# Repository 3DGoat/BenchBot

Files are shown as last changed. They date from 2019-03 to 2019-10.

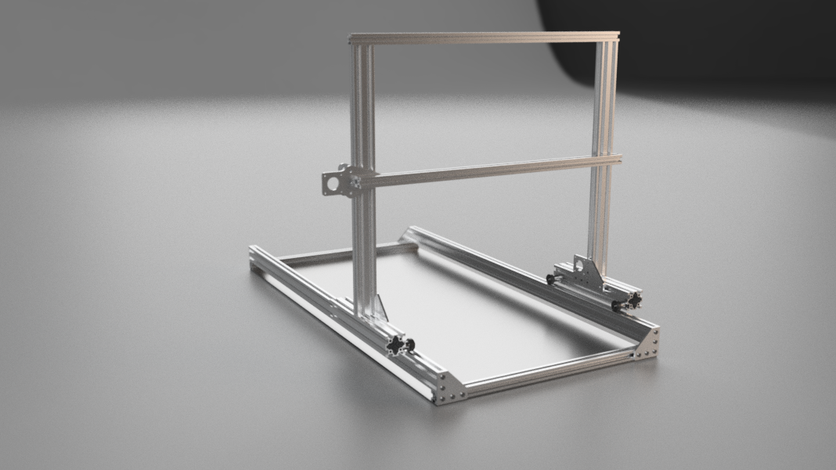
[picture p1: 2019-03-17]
Full Build v24 (2).png

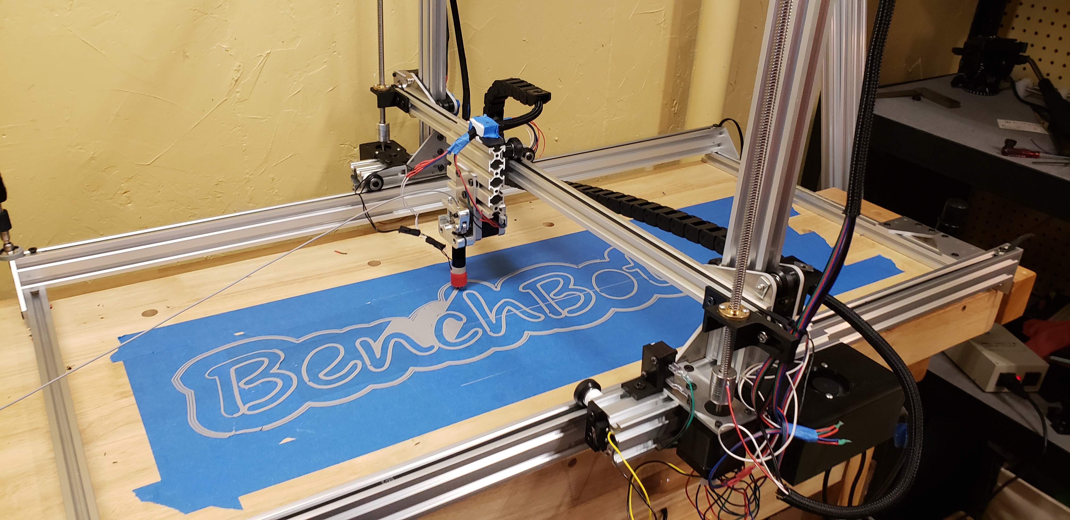
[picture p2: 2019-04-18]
20190323_132628.jpg

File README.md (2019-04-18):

# BenchBot
A large format 3D printer built specifically for a workbench. If files are marked experimental or untested that means that I have not tested them or they do not work. If files are unmarked you can assume that they will work.

Main sheet metal parts can be used on almost any length of aluminum extrusion.
Openbuilds 20x20,20x40 is suggested for this build. All metal parts are made for M5 screws and cheap v-slot wheels found on amazon
Sheet metal parts can be printed, but for best rigidity sheet metal would be suggested.

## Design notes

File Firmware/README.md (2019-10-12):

# Firmware

## 1.1.1
  Firmware made for full sized Benchbot.
  - Reverse logic for endstops (for manual homeing)
  - Steps/mm X,Y,Z,E  160, 80, 400, 96
  - Thermal settings set for Ubis 13s
  
## 1.1.2
  Firmware made for full sized Benchbot
  - Currently tested
    - Does not work with BLTouch
  - Default logic for enstops
  - Z settings made for BLTouch with mesh bed leveling
  - Steps/mm X,Y,Z,E  160, 80, 400, 96
  - Thermal settings set for Ubis 13s

## 1.1.3
   Firmware made for full sized Benchbot
  - Currently tested
  - Reverse logic for enstops
  - Z settings made for BLTouch with mesh bed leveling 4*4
  - Steps/mm X,Y,Z,E  160, 80, 400, 96
  - Thermal settings set for Ubis 13s
  - Last Version of Marlin
  
## 2.0 Duet wifi Config
   Firmware made for full sized BenchBot 
   - Currently Tested
   - Made for manual hinge Z-probe
   - Steps/mm X,Y,Z,E  160, 80, 400, 96
   - Thermal settings set for Ubis 13s
   - Sugguested mesh bed leveling spacing X=30 Y20

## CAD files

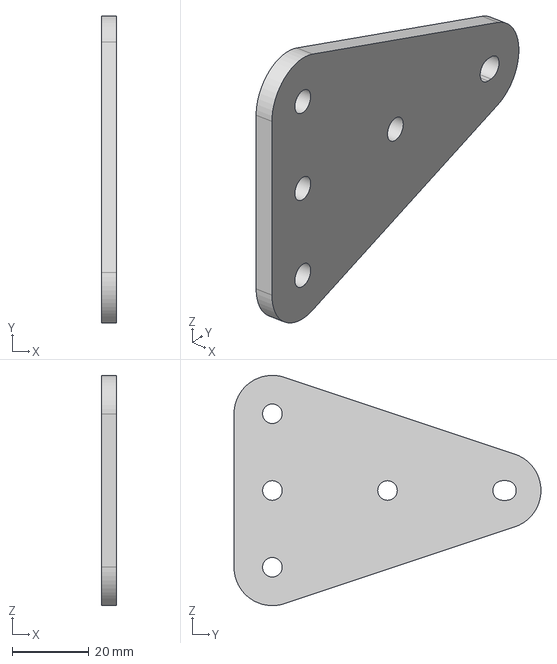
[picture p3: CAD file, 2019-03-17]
BenchBot CAD/Sheet Metal Parts/Main Y block v1.step
4.00 x 80.0 x 60.0 mm

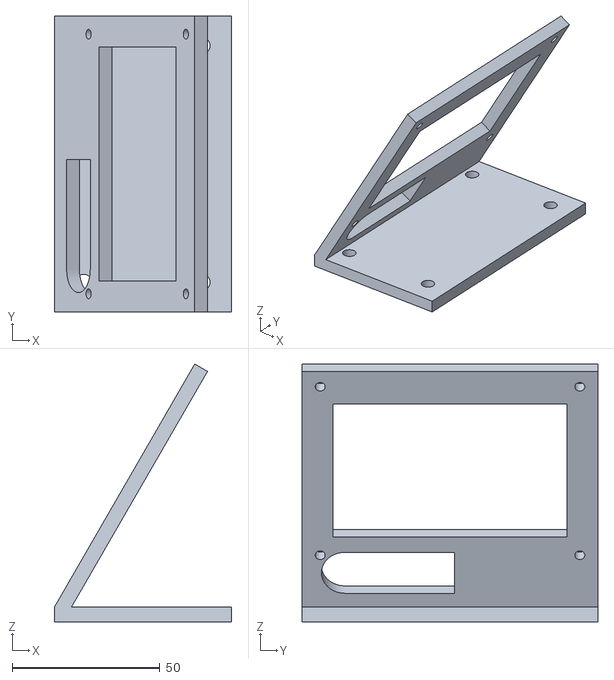
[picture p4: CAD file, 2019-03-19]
BenchBot CAD/Experimental parts/Controller.stl
60.0 x 100.0 x 87.3

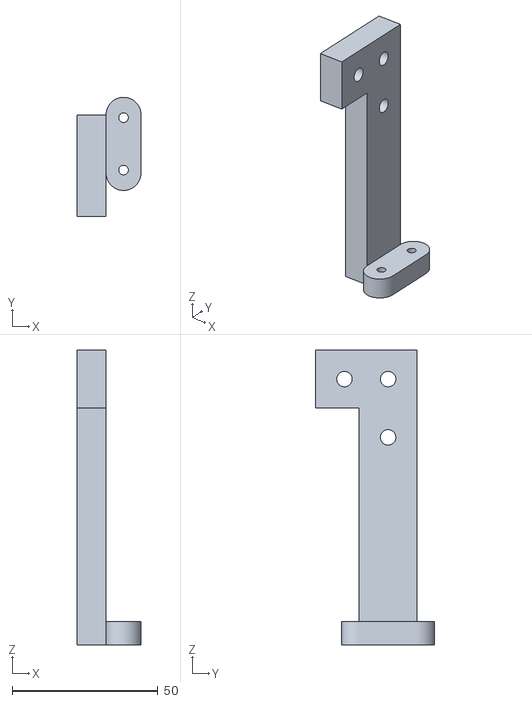
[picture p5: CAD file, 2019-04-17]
BenchBot CAD/STLs/Bltouch mount v2.stl
22.0 x 41.0 x 101.3

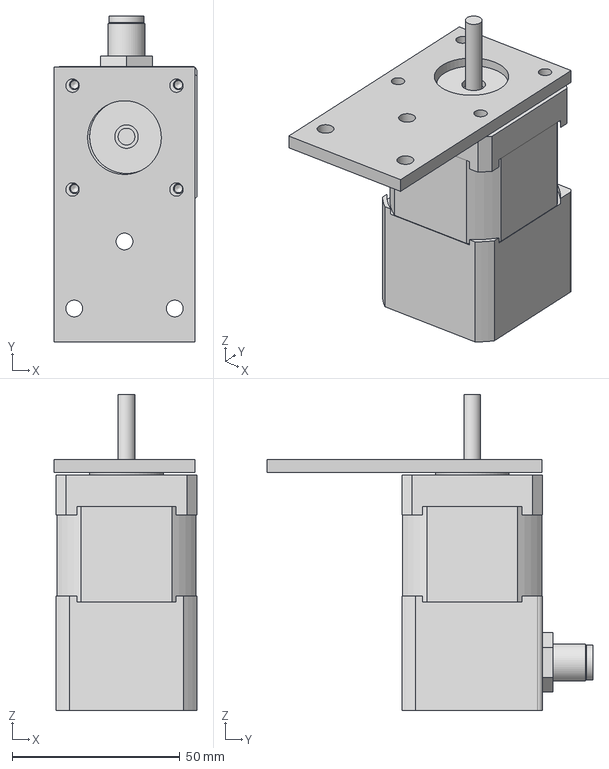
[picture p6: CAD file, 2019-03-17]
BenchBot CAD/Sheet Metal Parts/T-slot Stepper.step
42.6 x 97.3 x 94.4 mm

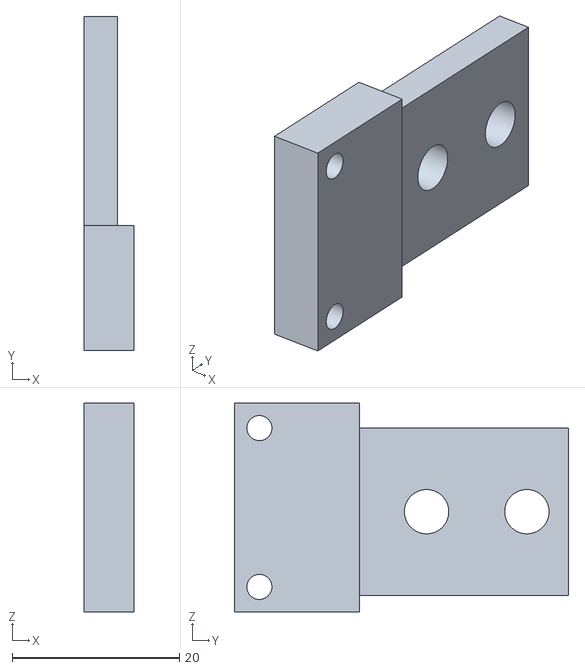
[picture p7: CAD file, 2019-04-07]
BenchBot CAD/STLs/Y endstop.stl
6.00 x 40.0 x 25.0

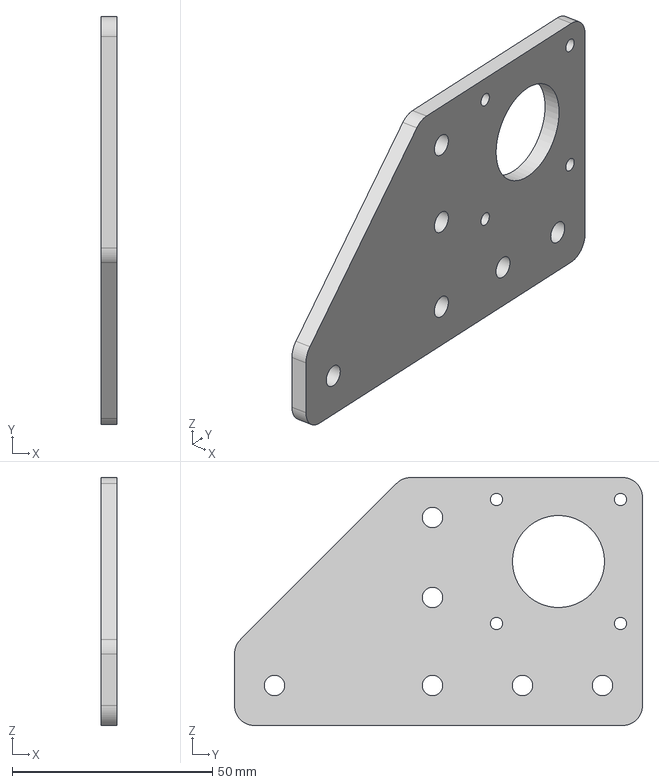
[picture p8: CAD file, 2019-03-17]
BenchBot CAD/Sheet Metal Parts/Bottom Gantry v5.step
4.00 x 102.0 x 62.0 mm

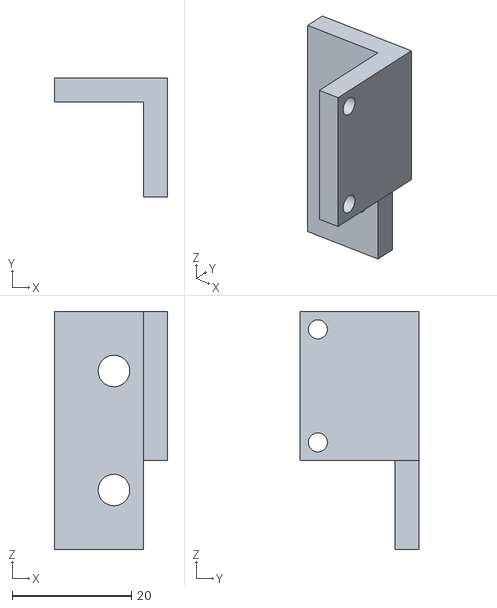
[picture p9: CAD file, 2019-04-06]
BenchBot CAD/STLs/X endstop.stl
19.0 x 20.0 x 40.0

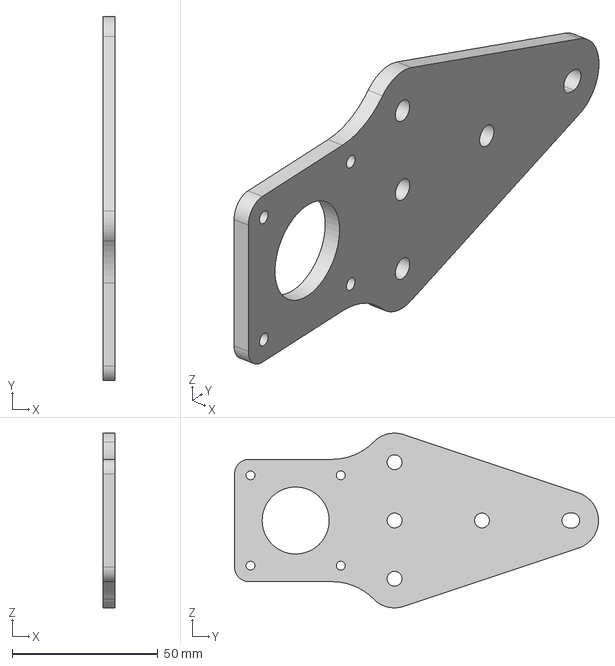
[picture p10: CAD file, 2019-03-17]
BenchBot CAD/Sheet Metal Parts/Motor Y block v3.step
4.00 x 125.0 x 60.0 mm

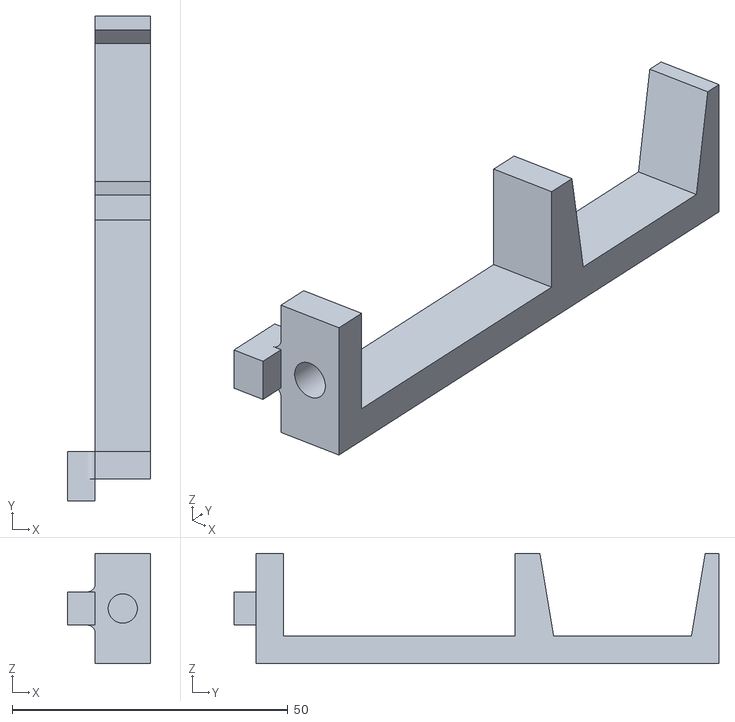
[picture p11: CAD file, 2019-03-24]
BenchBot CAD/STLs/Cable Chain Support.stl
15.0 x 88.0 x 20.0

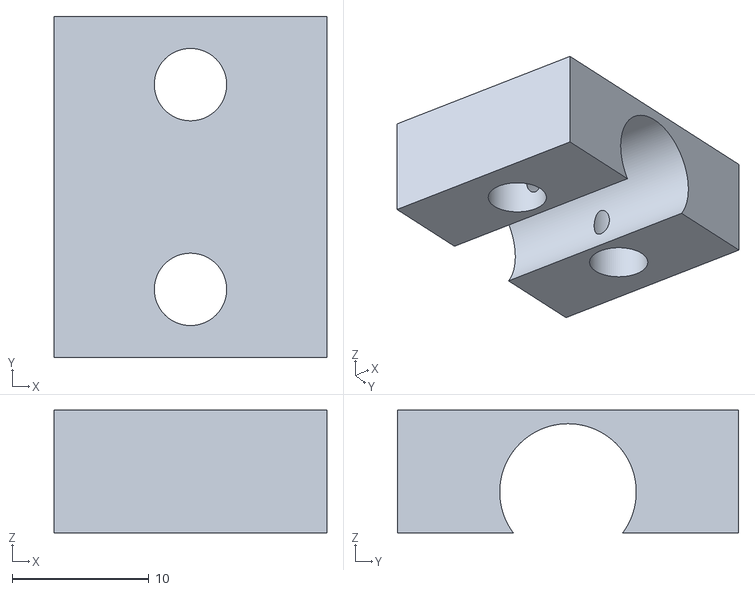
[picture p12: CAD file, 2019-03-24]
BenchBot CAD/STLs/Cable Chain Mount Y Strain Relief.stl
20.0 x 25.0 x 9.00

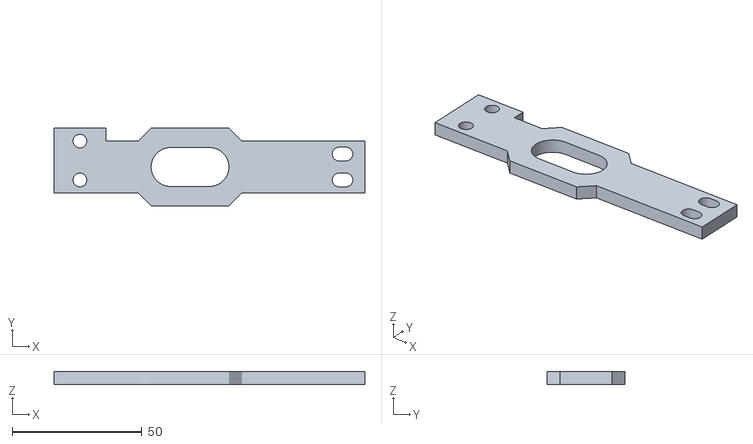
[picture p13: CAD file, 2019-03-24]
BenchBot CAD/STLs/Cable Chain Mount Y.stl
120.0 x 30.0 x 5.00

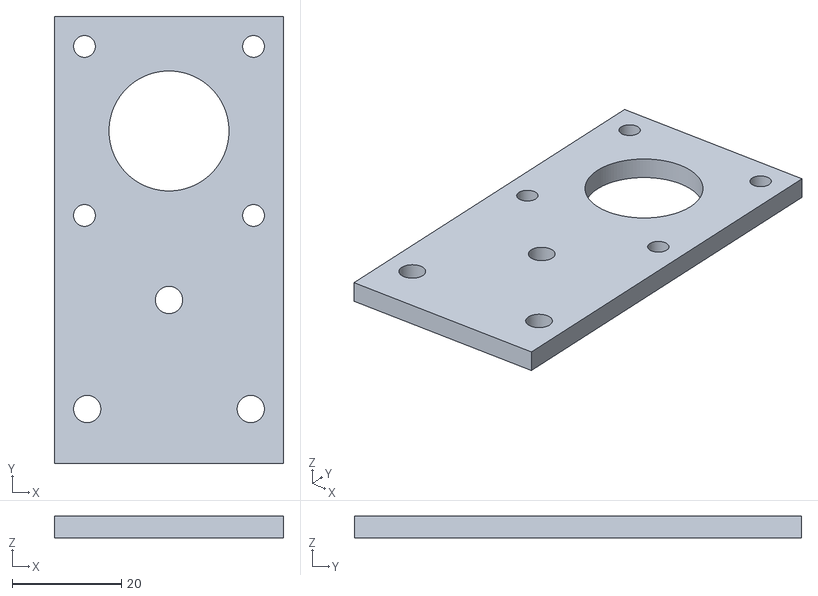
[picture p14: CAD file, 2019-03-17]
BenchBot CAD/STLs/T-slot Stepper.stl
42.0 x 82.0 x 4.00

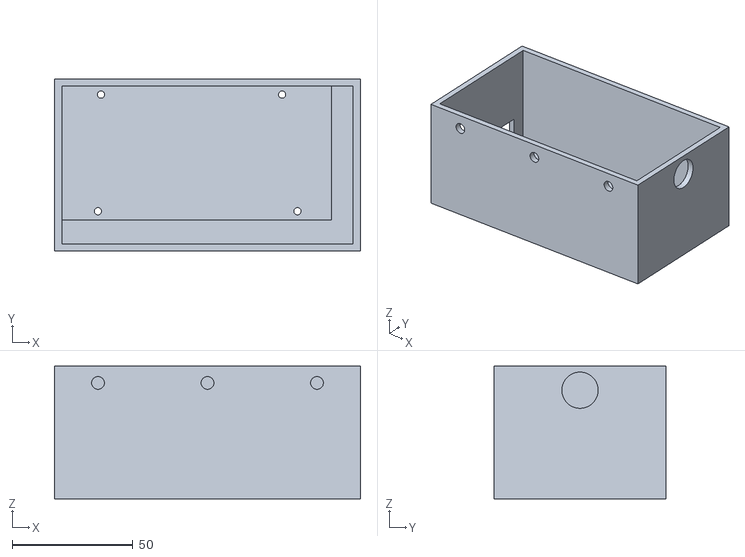
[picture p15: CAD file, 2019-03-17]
BenchBot CAD/STLs/RAMPS case BOTTOM.stl
126.6 x 71.3 x 55.0

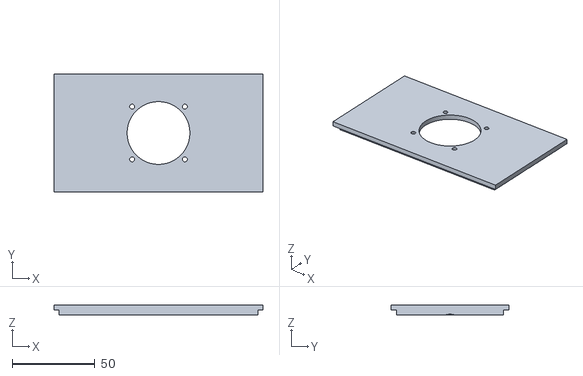
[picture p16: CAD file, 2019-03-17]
BenchBot CAD/STLs/RAMPS case TOP.stl
126.6 x 71.3 x 6.00

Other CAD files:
BenchBot CAD/Experimental parts/Y main block LIGHT.stl
BenchBot CAD/Experimental parts/Light Main Y block v2.step
BenchBot CAD/STLs/Main Y block V3.stl
BenchBot CAD/STLs/Motor Y Block V3.stl
BenchBot CAD/STLs/T-Slot Clip.stl
BenchBot CAD/STLs/Y Belt.stl
BenchBot CAD/STLs/Z Nut Y belt-end.stl

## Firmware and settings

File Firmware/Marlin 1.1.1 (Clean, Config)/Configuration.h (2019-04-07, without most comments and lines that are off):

#define CONFIGURATION_H
#define CONFIGURATION_H_VERSION 010109
#define STRING_CONFIG_H_AUTHOR "(none, default config)" // Who made the changes.
#define SHOW_BOOTSCREEN
#define STRING_SPLASH_LINE1 SHORT_BUILD_VERSION // will be shown during bootup in line 1
#define STRING_SPLASH_LINE2 WEBSITE_URL         // will be shown during bootup in line 2
#define SERIAL_PORT 0
#define BAUDRATE 250000
  #define MOTHERBOARD BOARD_RAMPS_14_EFF
#define CUSTOM_MACHINE_NAME "Bench Bot"
#define EXTRUDERS 1
#define DEFAULT_NOMINAL_FILAMENT_DIA 1.75
#define POWER_SUPPLY 0
#define TEMP_SENSOR_0 1
#define TEMP_SENSOR_1 0
#define TEMP_SENSOR_2 0
#define TEMP_SENSOR_3 0
#define TEMP_SENSOR_4 0
#define TEMP_SENSOR_BED 0
#define TEMP_SENSOR_CHAMBER 0
#define DUMMY_THERMISTOR_998_VALUE 25
#define DUMMY_THERMISTOR_999_VALUE 100
#define MAX_REDUNDANT_TEMP_SENSOR_DIFF 10
#define TEMP_RESIDENCY_TIME 10  // (seconds)
#define TEMP_HYSTERESIS 3       // (degC) range of +/- temperatures considered "close" to the target one
#define TEMP_WINDOW     1       // (degC) Window around target to start the residency timer x degC early.
#define TEMP_BED_RESIDENCY_TIME 10  // (seconds)
#define TEMP_BED_HYSTERESIS 3       // (degC) range of +/- temperatures considered "close" to the target one
#define TEMP_BED_WINDOW     1       // (degC) Window around target to start the residency timer x degC early.
#define HEATER_0_MINTEMP 5
#define HEATER_1_MINTEMP 5
#define HEATER_2_MINTEMP 5
#define HEATER_3_MINTEMP 5
#define HEATER_4_MINTEMP 5
#define BED_MINTEMP 5
#define HEATER_0_MAXTEMP 250
#define HEATER_1_MAXTEMP 275
#define HEATER_2_MAXTEMP 275
#define HEATER_3_MAXTEMP 275
#define HEATER_4_MAXTEMP 275
#define BED_MAXTEMP 150
#define PIDTEMP
#define BANG_MAX 255     // Limits current to nozzle while in bang-bang mode; 255=full current
#define PID_MAX BANG_MAX // Limits current to nozzle while PID is active (see PID_FUNCTIONAL_RANGE below); 255=full current
#define PID_K1 0.95      // Smoothing factor within any PID loop
  #define PID_FUNCTIONAL_RANGE 10 // If the temperature difference between the target temperature and the actual temperature
  #define DEFAULT_Kp 22.2
  #define DEFAULT_Ki 1.08
  #define DEFAULT_Kd 114
#define MAX_BED_POWER 255 // limits duty cycle to bed; 255=full current
#define PREVENT_COLD_EXTRUSION
#define EXTRUDE_MINTEMP 170
#define PREVENT_LENGTHY_EXTRUDE
#define EXTRUDE_MAXLENGTH 200
#define THERMAL_PROTECTION_HOTENDS // Enable thermal protection for all extruders
#define THERMAL_PROTECTION_BED     // Enable thermal protection for the heated bed
#define USE_XMIN_PLUG
#define USE_YMIN_PLUG
#define USE_ZMIN_PLUG
#define ENDSTOPPULLUPS
#define X_MIN_ENDSTOP_INVERTING true // set to true to invert the logic of the endstop.
#define Y_MIN_ENDSTOP_INVERTING true // set to true to invert the logic of the endstop.
#define Z_MIN_ENDSTOP_INVERTING true // set to true to invert the logic of the endstop.
#define X_MAX_ENDSTOP_INVERTING false // set to true to invert the logic of the endstop.
#define Y_MAX_ENDSTOP_INVERTING false // set to true to invert the logic of the endstop.
#define Z_MAX_ENDSTOP_INVERTING false // set to true to invert the logic of the endstop.
#define Z_MIN_PROBE_ENDSTOP_INVERTING false // set to true to invert the logic of the probe.
#define X_DRIVER_TYPE  A4988
#define Y_DRIVER_TYPE  A4988
#define DEFAULT_AXIS_STEPS_PER_UNIT   { 160, 80, 400, 96 }
#define DEFAULT_MAX_FEEDRATE          { 120, 200, 10, 25 }
#define DEFAULT_MAX_ACCELERATION      { 301, 1000, 100, 10000 }
#define DEFAULT_ACCELERATION          150    // X, Y, Z and E acceleration for printing moves
#define DEFAULT_RETRACT_ACCELERATION  3000    // E acceleration for retracts
#define DEFAULT_TRAVEL_ACCELERATION   175    // X, Y, Z acceleration for travel (non printing) moves
#define DEFAULT_XJERK                  5.0
#define DEFAULT_YJERK                 10.0
#define DEFAULT_ZJERK                  0.3
#define DEFAULT_EJERK                  5.0
#define PROBE_MANUALLY
#define MANUAL_PROBE_START_Z 0.2
#define X_PROBE_OFFSET_FROM_EXTRUDER 10  // X offset: -left  +right  [of the nozzle]
#define Y_PROBE_OFFSET_FROM_EXTRUDER 10  // Y offset: -front +behind [the nozzle]
#define Z_PROBE_OFFSET_FROM_EXTRUDER 0   // Z offset: -below +above  [the nozzle]
#define MIN_PROBE_EDGE 10
#define XY_PROBE_SPEED 3600
#define Z_PROBE_SPEED_FAST HOMING_FEEDRATE_Z
#define Z_PROBE_SPEED_SLOW (Z_PROBE_SPEED_FAST / 2)
#define Z_CLEARANCE_DEPLOY_PROBE   10 // Z Clearance for Deploy/Stow
#define Z_CLEARANCE_BETWEEN_PROBES  5 // Z Clearance between probe points
#define Z_CLEARANCE_MULTI_PROBE     5 // Z Clearance between multiple probes
#define Z_PROBE_LOW_POINT          -2 // Farthest distance below the trigger-point to go before stopping
#define Z_PROBE_OFFSET_RANGE_MIN -20
#define Z_PROBE_OFFSET_RANGE_MAX 20
#define X_ENABLE_ON 0
#define Y_ENABLE_ON 0
#define Z_ENABLE_ON 0
#define E_ENABLE_ON 0 // For all extruders
#define DISABLE_X false
#define DISABLE_Y false
#define DISABLE_Z false
#define DISABLE_E false // For all extruders
#define DISABLE_INACTIVE_EXTRUDER true // Keep only the active extruder enabled.
#define INVERT_X_DIR false
#define INVERT_Y_DIR true
#define INVERT_Z_DIR false
#define INVERT_E0_DIR false
#define INVERT_E1_DIR false
#define INVERT_E2_DIR false
#define INVERT_E3_DIR false
#define INVERT_E4_DIR false
#define X_HOME_DIR -1
#define Y_HOME_DIR -1
#define Z_HOME_DIR -1
#define X_BED_SIZE 690
#define Y_BED_SIZE 440
#define X_MIN_POS 0
#define Y_MIN_POS 0
#define Z_MIN_POS 0
#define X_MAX_POS X_BED_SIZE
#define Y_MAX_POS Y_BED_SIZE
#define Z_MAX_POS 250
#define MIN_SOFTWARE_ENDSTOPS
  #define MIN_SOFTWARE_ENDSTOP_X
  #define MIN_SOFTWARE_ENDSTOP_Y
  #define MIN_SOFTWARE_ENDSTOP_Z
#define MAX_SOFTWARE_ENDSTOPS
  #define MAX_SOFTWARE_ENDSTOP_X
  #define MAX_SOFTWARE_ENDSTOP_Y
  #define MAX_SOFTWARE_ENDSTOP_Z
#define MESH_BED_LEVELING
  #define ENABLE_LEVELING_FADE_HEIGHT
  #define SEGMENT_LEVELED_MOVES
  #define LEVELED_SEGMENT_LENGTH 5.0 // (mm) Length of all segments (except the last one)
  #define MESH_INSET 10          // Set Mesh bounds as an inset region of the bed
  #define GRID_MAX_POINTS_X 3    // Don't use more than 7 points per axis, implementation limited.
  #define GRID_MAX_POINTS_Y GRID_MAX_POINTS_X
#define LCD_BED_LEVELING
  #define MBL_Z_STEP 0.1    // Step size while manually probing Z axis.
  #define LCD_PROBE_Z_RANGE 4 // Z Range centered on Z_MIN_POS for LCD Z adjustment
#define MANUAL_X_HOME_POS 0
#define MANUAL_Y_HOME_POS 0
#define MANUAL_Z_HOME_POS 0
#define HOMING_FEEDRATE_XY (50*60)
#define HOMING_FEEDRATE_Z  (4*60)
#define EEPROM_CHITCHAT   // Give feedback on EEPROM commands. Disable to save PROGMEM.
#define HOST_KEEPALIVE_FEATURE        // Disable this if your host doesn't like keepalive messages
#define DEFAULT_KEEPALIVE_INTERVAL 2  // Number of seconds between "busy" messages. Set with M113.
#define BUSY_WHILE_HEATING            // Some hosts require "busy" messages even during heating
#define PREHEAT_1_TEMP_HOTEND 180
#define PREHEAT_1_TEMP_BED      0
#define PREHEAT_1_FAN_SPEED     0 // Value from 0 to 255
#define PREHEAT_2_TEMP_HOTEND 240
#define PREHEAT_2_TEMP_BED      0
#define PREHEAT_2_FAN_SPEED     0 // Value from 0 to 255
#define PRINTJOB_TIMER_AUTOSTART
#define LCD_LANGUAGE en
#define DISPLAY_CHARSET_HD44780 JAPANESE
#define SDSUPPORT
#define SPI_SPEED SPI_HALF_SPEED
#define REPRAP_DISCOUNT_FULL_GRAPHIC_SMART_CONTROLLER
#define SOFT_PWM_SCALE 0
#define SERVO_DELAY { 300 }

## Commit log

2019-03-17 Create CAD
2019-03-17 Most CAD files for the printer
    Sheet metal parts have holes made for M5, they are all 5.1mm witch is a bit tight for most manufacturing facilities.
    [Bottom Gantry v5.step, Main Y block V3.stl, Main Y block v1.step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]
2019-03-17 The Experimental Zone
    These parts have not been tested/printed by myself, so there may be large errors.
    Y block light is designed to be threaded on two of the wheel mounting holes.
    [Light Main Y block v2.step, Y main block LIGHT.stl]
2019-04-06 New X endstop
    [X endstop.stl]
2019-04-07 BLTouch Mounting bracket
    Made to mount on the 20x80 extrusion used for the Y carriage. standoff made for Ubis 13s with Alu v1 extuder.
    [Bltouch mount v1.stl]
2019-04-07 Y endstop
    New Y endstop for Bigtree micro switch enstops
    [Y endstop.stl]
2019-04-07 Create Marlin V1.1.1
2019-04-14 Marlin 1.1.3 (experimental)
    Marlin 1.1.3 BLTouch compatibility.
    [Configuration.h, Configuration_adv.h]
2019-04-14 Marlin 1.1.3 (experimental)
    Supports BLTouch Z probe
    [Configuration.h, Configuration_adv.h]
2019-04-17 Not long enough for ubis 13s
    [Bltouch mount v1.stl]
2019-04-17 Add files via upload
    New longer BLTouch arm
    [Bltouch mount v2.stl]

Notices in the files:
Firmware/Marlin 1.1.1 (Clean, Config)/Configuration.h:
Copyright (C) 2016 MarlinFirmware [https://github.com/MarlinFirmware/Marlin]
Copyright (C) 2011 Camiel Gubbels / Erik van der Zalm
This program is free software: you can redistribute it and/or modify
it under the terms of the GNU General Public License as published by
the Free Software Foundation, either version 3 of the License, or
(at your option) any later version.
